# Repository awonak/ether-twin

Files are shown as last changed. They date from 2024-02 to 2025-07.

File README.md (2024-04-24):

# Ether Twin

A platform for sharing control voltage and audio over RJ45 shielded network cable

Note: These modules are still a work in progress and may contain errors.

## Ether Twin v1 - Stand-alone

Stand-alone passive desktop version.

Follow the ibom component placement guide [here](https://htmlpreview.github.io/?https://github.com/awonak/ether-twin/blob/main/ether_v1/bom/ibom.html).

Step by step build guide [here](ether_v1/README.md).

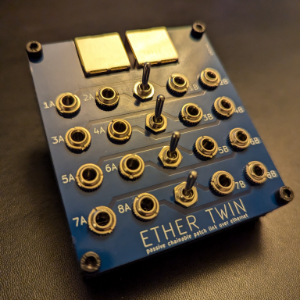
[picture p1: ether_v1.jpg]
Stand-alone Ether Twin v1


## Ether Twin v2 - 3U

Rack mount 3U 10HP version

*Photo Coming Soon*

## Ether Mix - Stand-alone

Stand-alone passive mixer

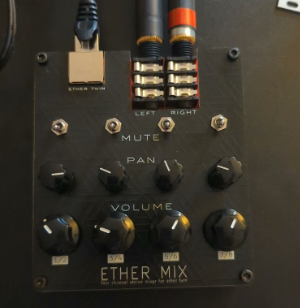
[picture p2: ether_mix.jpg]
ether-mix Ether Mix


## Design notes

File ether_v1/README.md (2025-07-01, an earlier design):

# Ether Twin v1

Tutorial Video:
https://youtu.be/pQHyfLVjiQw?si=90aeZab5XTt6bDr_

## Bill of Materials

| Reference(s) | Qty | Value | Supplier Link |
|-|-|-|-|
| J1 - J16  | 16 | Thonkiconn 3.5mm Mono Jack | https://www.thonk.co.uk/shop/thonkiconn/ |
| J17, J18 | 2 | Ethernet Connectors | https://www.mouser.com/ProductDetail/571-1-406541-5 |
| S1, S2, S3, S4 | 4 | DPDT Switch ON-ON | https://www.thonk.co.uk/shop/sub-mini-toggle-switches/ |
| S5 | 1 | 1PDT Slide Swith ON-ON | https://www.mouser.com/ProductDetail/611-JS102011SAQN |

## Build Guide v1.2

### Solder the components to the main PCB

Follow the ibom component placement guide [here](https://htmlpreview.github.io/?https://github.com/awonak/ether-twin/blob/main/ether_v1/bom/ibom.html).

1. Start by soldering the Ground Select switch S5

1. Place the two Ethernet Jacks. Begin by tacking one mounting hole lug on each Ethernet Jack. Press firmly on the jack while heating the tacked solder to ensure a snug fit.

1. Once the Ethernet Jack lugs are soldered and the jacks are flush against the PCB, then proceed to solder the 8 jack pins. (Pro tip; smear a bit of rosin flux against the pins, then drag a large bead of solder across the pins.)

1. Next, place all 16 cv jacks on the PCB. Attach the top panel, and screw nuts on the 4 corner jacks to hold them in place. Now you can flip the module over and lay it down flat while soldering the cv jacks.

1. (v1.2+ only) Remove the top panel and place the 4 toggle switches. Place the top panel back on and screw on the same 4 corner nut jacks and the 4 switch nuts. Flip the module over and solder the 4 toggle switches. (Either carefully rest the module against one side of the toggle switches, or use a third-hand to hold the module.)

### Assemble the enclosure

1. Remove the top panel attached during the previous step. This will make it easier to attach the standoffs later.

1. Start by threading the loger M3 screws through the 4 mounting holes of the bottom panel.

1. Tighten the M3 nut against those screws.

1. Place the components PCB against the nuts, components facing up.

1. Tighten the 10mm nylon standoffs to the bottom panel screws sticking up from the components PCB.

1. Attach the top panel to the component pcb and screw on all 16 cv jack nuts and 4 toggle switch nuts.

1. Screw the shorter M3 screws into the top panel mounting holes and into the standoffs.

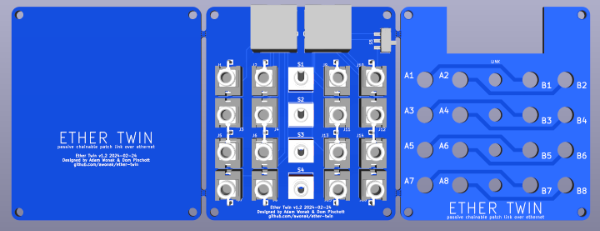
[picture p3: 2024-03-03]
ether_v1.png

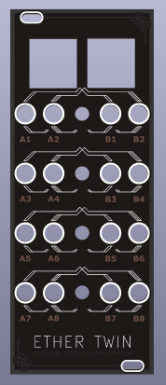
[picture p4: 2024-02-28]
ether_v2_panel.png

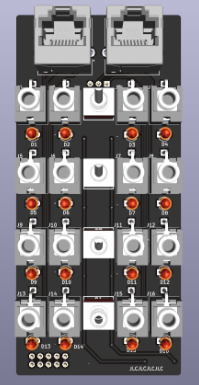
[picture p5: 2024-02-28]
ether_v2_front.png

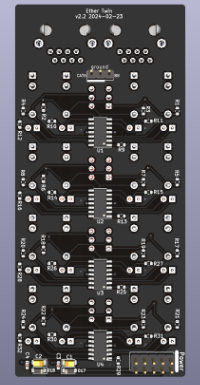
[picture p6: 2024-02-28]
ether_v2_back.png

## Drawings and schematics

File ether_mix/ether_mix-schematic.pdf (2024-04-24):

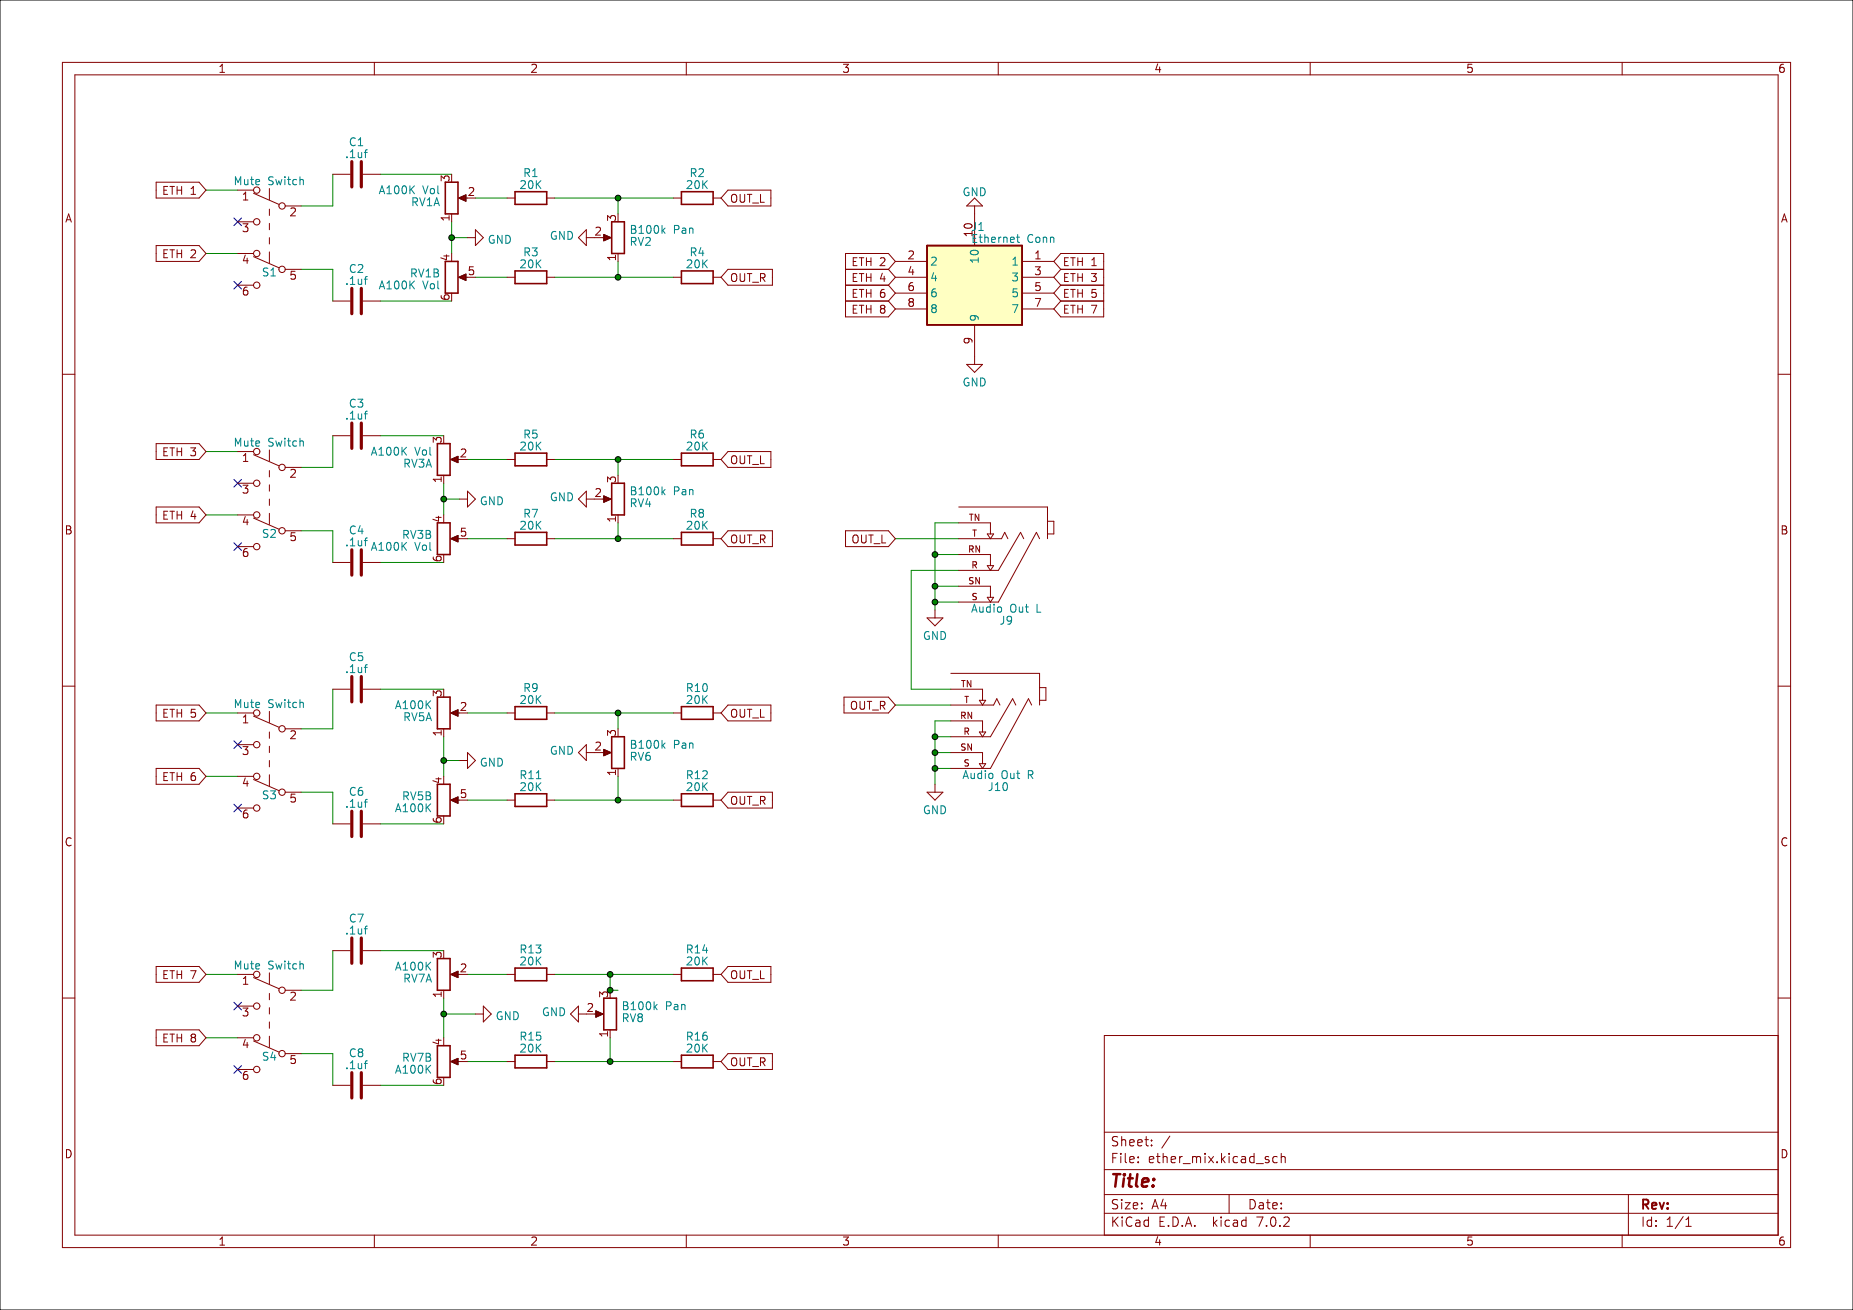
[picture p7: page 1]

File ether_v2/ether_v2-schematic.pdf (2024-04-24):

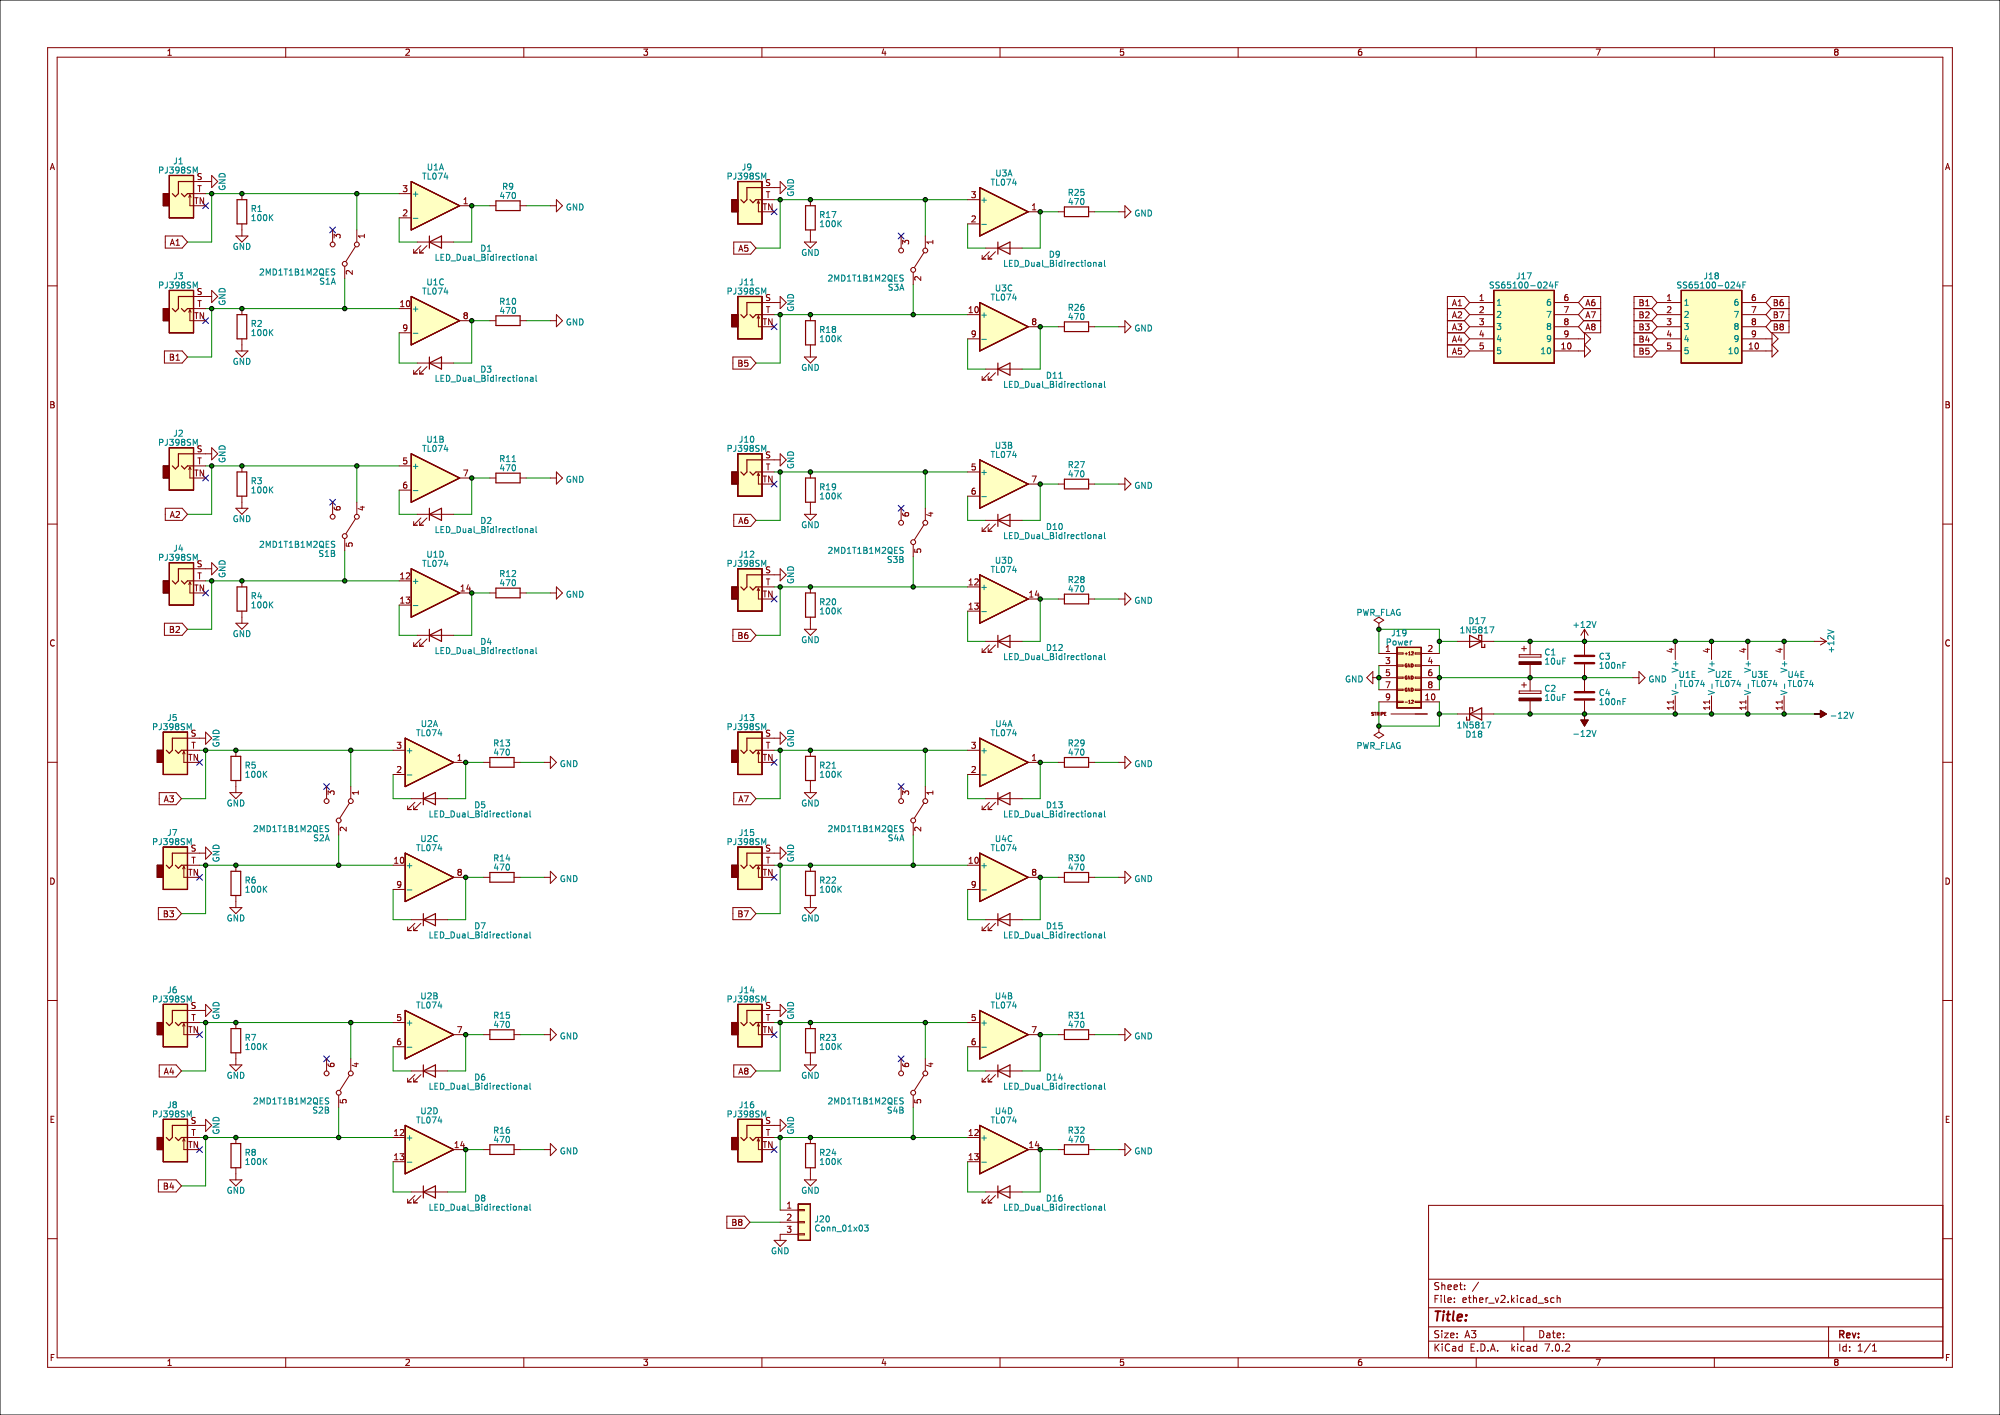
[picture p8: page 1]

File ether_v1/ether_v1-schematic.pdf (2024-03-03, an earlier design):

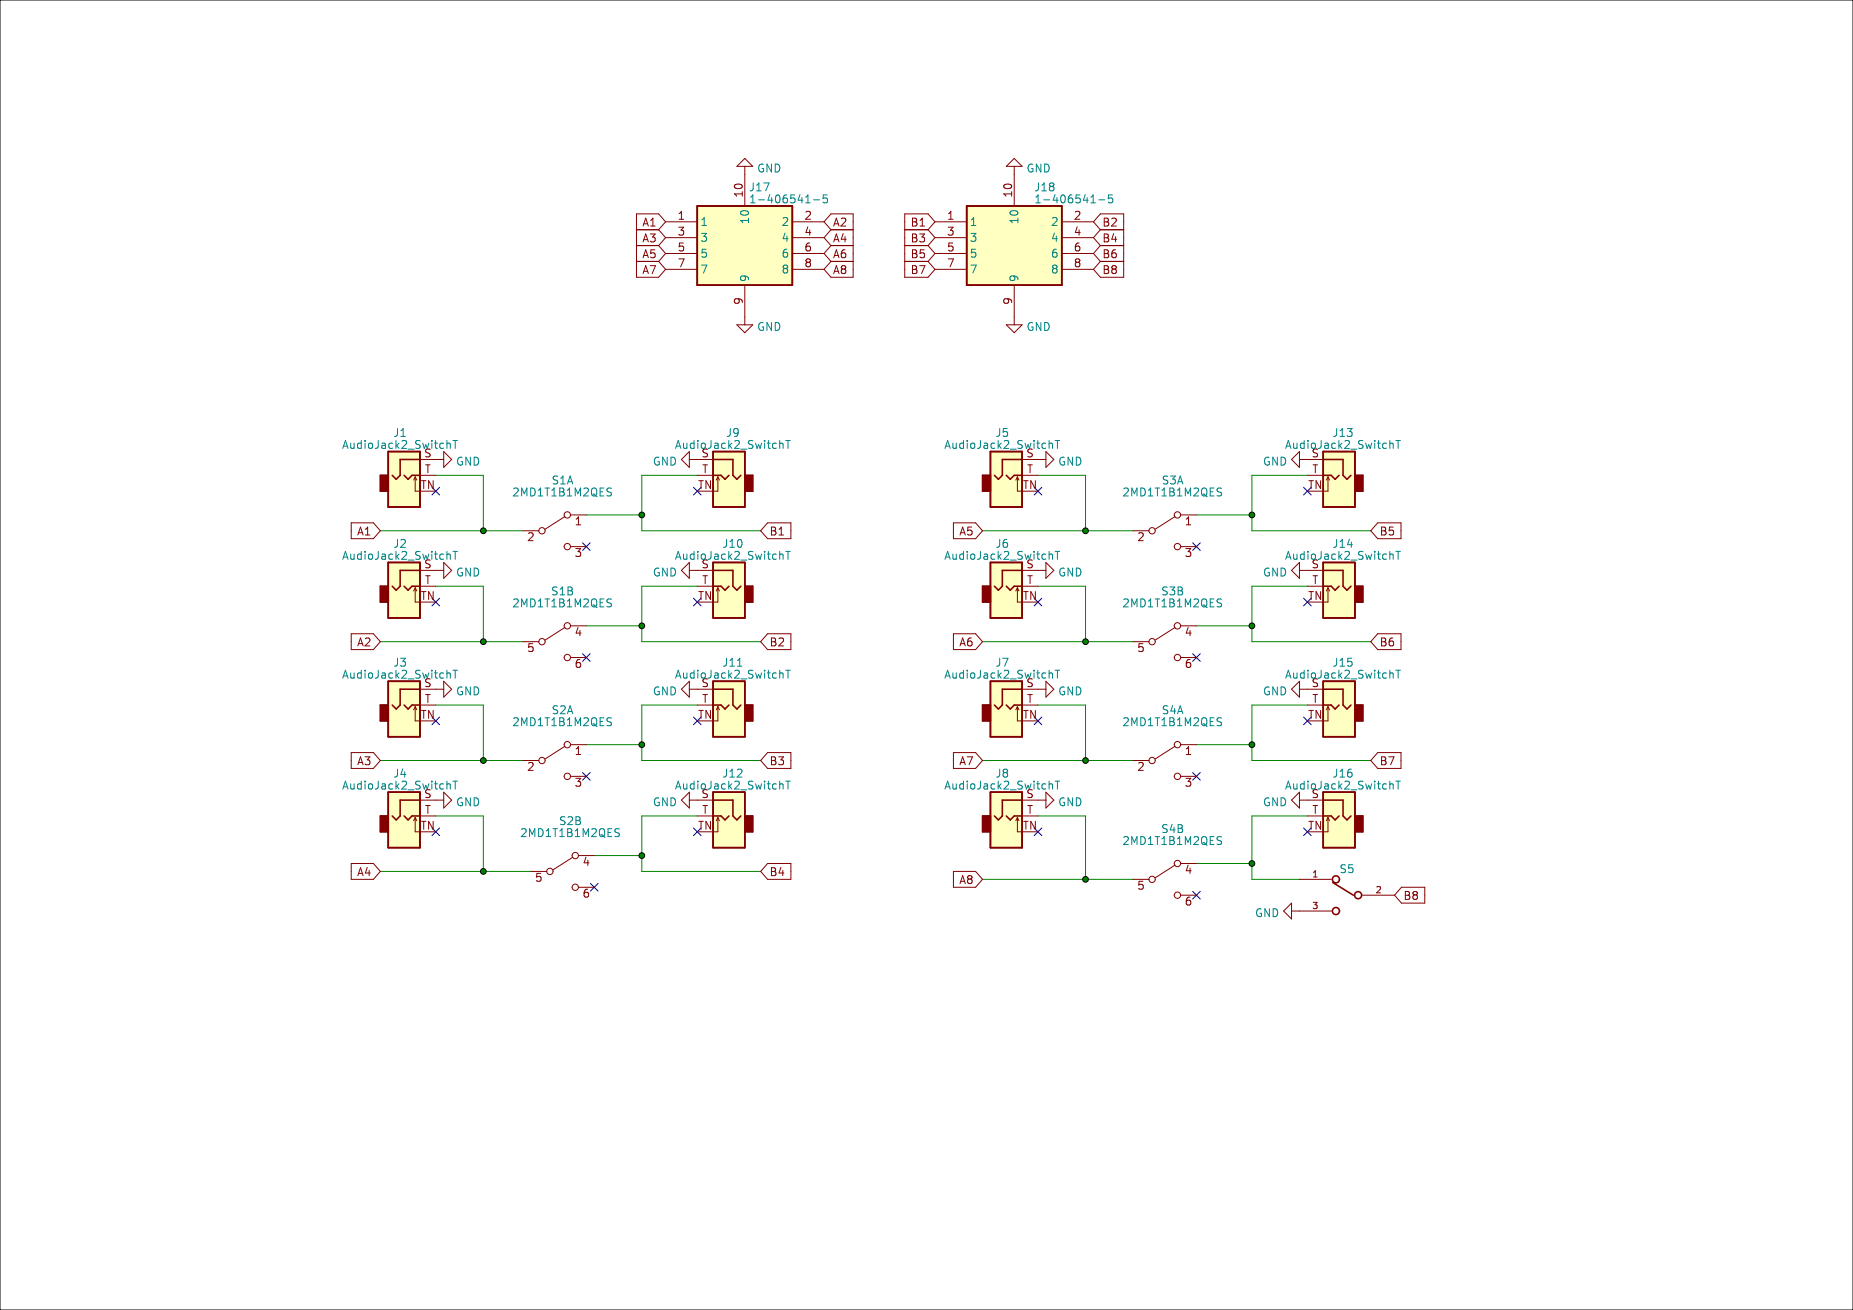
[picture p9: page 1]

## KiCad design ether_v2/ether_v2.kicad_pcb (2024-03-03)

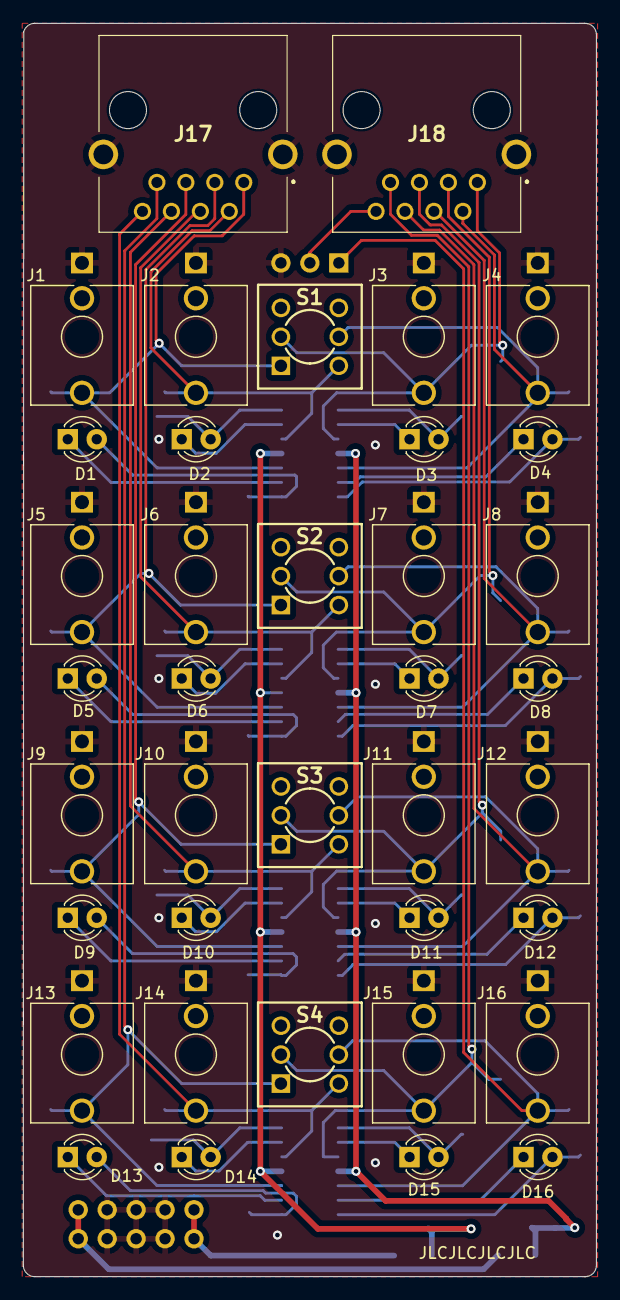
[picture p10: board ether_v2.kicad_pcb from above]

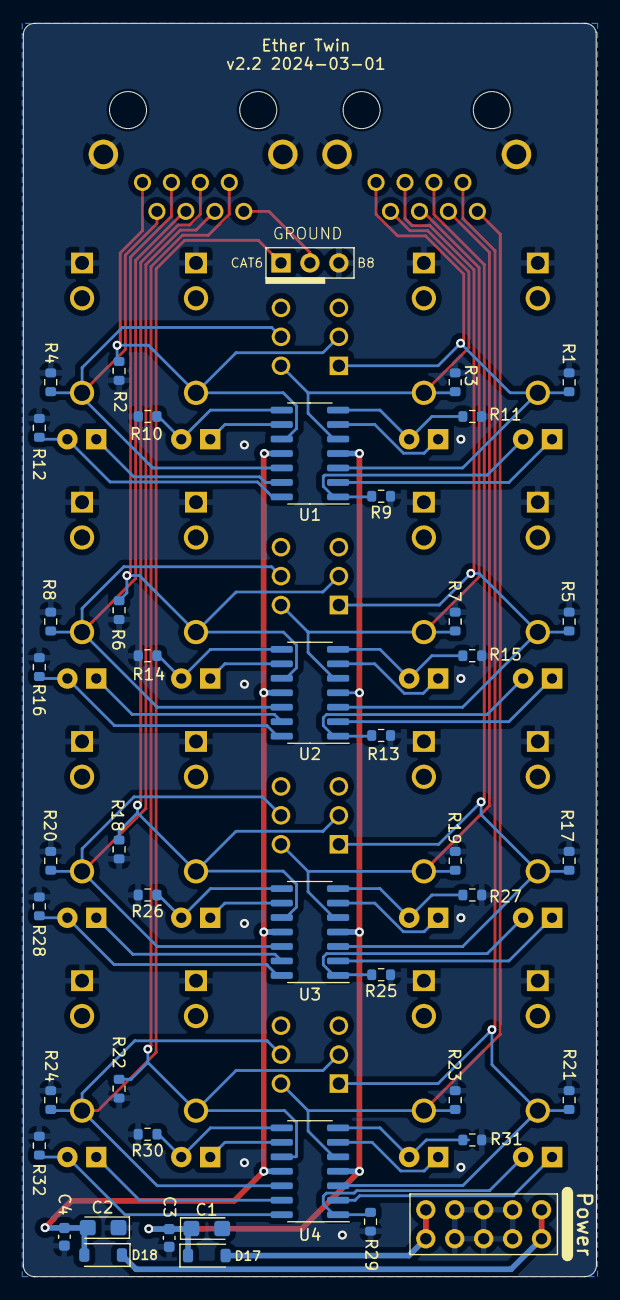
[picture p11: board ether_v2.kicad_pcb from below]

Board: 2 copper layers, 50.3 x 110.0 mm, 82 parts (44 on the bottom side), 54 nets.

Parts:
C1, C2: 10uF; CP_EIA-3216-18_Kemet-A
C3, C4: 100nF; C_0603_1608Metric
D1, D2, D3, D4, D5, D6, D7, D8, D9, D10, D11, D12, D13, D14, D15, D16: LED_Dual_Bidirectional; LED_D3.0mm
D17, D18: 1N5817; D_SOD-123
J1, J2, J3, J4, J5, J6, J7, J8, J9, J10, J11, J12, J13, J14, J15, J16: PJ398SM; Jack_3.5mm_QingPu_WQP-PJ398SM_Vertical_CircularHoles_3dModel
J17, J18: SS65100-024F; SS65100024F
J19: Power; Pins_2x05_2.54mm_TH_Europower
J20: Conn_01x03; PinHeader_1x03_P2.54mm_Vertical
R1, R2, R3, R4, R5, R6, R7, R8, R17, R18, R19, R20, R21, R22, R23, R24: 100K; R_0603_1608Metric
R9, R10, R11, R12, R13, R14, R15, R16, R25, R26, R27, R28, R29, R30, R31, R32: 470; R_0603_1608Metric
S1, S2, S3, S4: 2MD1T1B1M2QES
U1, U2, U3, U4: TL074; SO-14_3.9x8.65mm_P1.27mm

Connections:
+12V: C1.1, C3.1, D17.1 (K), U1.4 (V+), U2.4 (V+), U3.4 (V+), U4.4 (V+)
-12V: C2.2, C4.2, D18.2 (A), U1.11 (V-), U2.11 (V-), U3.11 (V-), U4.11 (V-)
A1: J1.T, J17.1, R1.2, S1.1 (A), U1.3 (+)
A2: J2.T, J17.2, R3.2, S1.4 (A), U1.5 (+)
A3: J5.T, J17.3, R5.2, S2.1 (A), U2.3 (+)
A4: J6.T, J17.4, R7.2, S2.4 (A), U2.5 (+)
A5: J9.T, J17.5, R17.2, S3.1 (A), U3.3 (+)
A6: J10.T, J17.6, R19.2, S3.4 (A), U3.5 (+)
A7: J13.T, J17.7, R21.2, S4.1 (A), U4.3 (+)
A8: J14.T, J17.8, R23.2, S4.4 (A), U4.5 (+)
B1: J3.T, J18.1, R2.2, S1.2 (B), U1.10 (+)
B2: J4.T, J18.2, R4.2, S1.5 (B), U1.12 (+)
B3: J7.T, J18.3, R6.2, S2.2 (B), U2.10 (+)
B4: J8.T, J18.4, R8.2, S2.5 (B), U2.12 (+)
B5: J11.T, J18.5, R18.2, S3.2 (B), U3.10 (+)
B6: J12.T, J18.6, R20.2, S3.5 (B), U3.12 (+)
B7: J15.T, J18.7, R22.2, S4.2 (B), U4.10 (+)
B8: J18.8, J20.2
GND: C1.2, C2.1, C3.2, C4.1, J1.S, J2.S, J3.S, J4.S, J5.S, J6.S, J7.S, J8.S, J9.S, J10.S, J11.S, J12.S, J13.S, J14.S, J15.S, J16.S, J17.9, J17.10, J18.9, J18.10, J19.3 (GND), J19.4 (GND), J19.5 (GND), J19.6 (GND), J19.7 (GND), J19.8 (GND), J20.3, R1.1, R2.1, R3.1, R4.1, R5.1, R6.1, R7.1, R8.1, R9.1, R10.2, R11.1, R12.2, R13.1, R14.2, R15.1, R16.2, R17.1, R18.1, R19.1, R20.1, R21.1, R22.1, R23.1, R24.1, R25.1, R26.2, R27.1, R28.2, R29.1, R30.2, R31.1, R32.2
unnamed: D1.2 (A), R9.2, U1.1
unnamed: D1.1 (K), U1.2 (-)
unnamed: D2.2 (A), R11.2, U1.7
unnamed: D2.1 (K), U1.6 (-)
unnamed: D3.2 (A), R10.1, U1.8
unnamed: D3.1 (K), U1.9 (-)
unnamed: D4.2 (A), R12.1, U1.14
unnamed: D4.1 (K), U1.13 (-)
unnamed: D5.2 (A), R13.2, U2.1
unnamed: D5.1 (K), U2.2 (-)
unnamed: D6.2 (A), R15.2, U2.7
unnamed: D6.1 (K), U2.6 (-)
unnamed: D7.2 (A), R14.1, U2.8
unnamed: D7.1 (K), U2.9 (-)
unnamed: D8.2 (A), R16.1, U2.14
unnamed: D8.1 (K), U2.13 (-)
unnamed: D9.2 (A), R25.2, U3.1
unnamed: D9.1 (K), U3.2 (-)
unnamed: D10.2 (A), R27.2, U3.7
unnamed: D10.1 (K), U3.6 (-)
unnamed: D11.2 (A), R26.1, U3.8
unnamed: D11.1 (K), U3.9 (-)
unnamed: D12.2 (A), R28.1, U3.14
unnamed: D12.1 (K), U3.13 (-)
unnamed: D13.2 (A), R29.2, U4.1
unnamed: D13.1 (K), U4.2 (-)
unnamed: D14.2 (A), R31.2, U4.7
unnamed: D14.1 (K), U4.6 (-)
unnamed: D15.2 (A), R30.1, U4.8
unnamed: D15.1 (K), U4.9 (-)
unnamed: D16.2 (A), R32.1, U4.14
unnamed: D16.1 (K), U4.13 (-)
unnamed: D17.2 (A), J19.1 (+12V), J19.2 (+12V)
unnamed: D18.1 (K), J19.9 (-12V), J19.10 (-12V)
unnamed: J16.T, J20.1, R24.2, S4.5 (B), U4.12 (+)

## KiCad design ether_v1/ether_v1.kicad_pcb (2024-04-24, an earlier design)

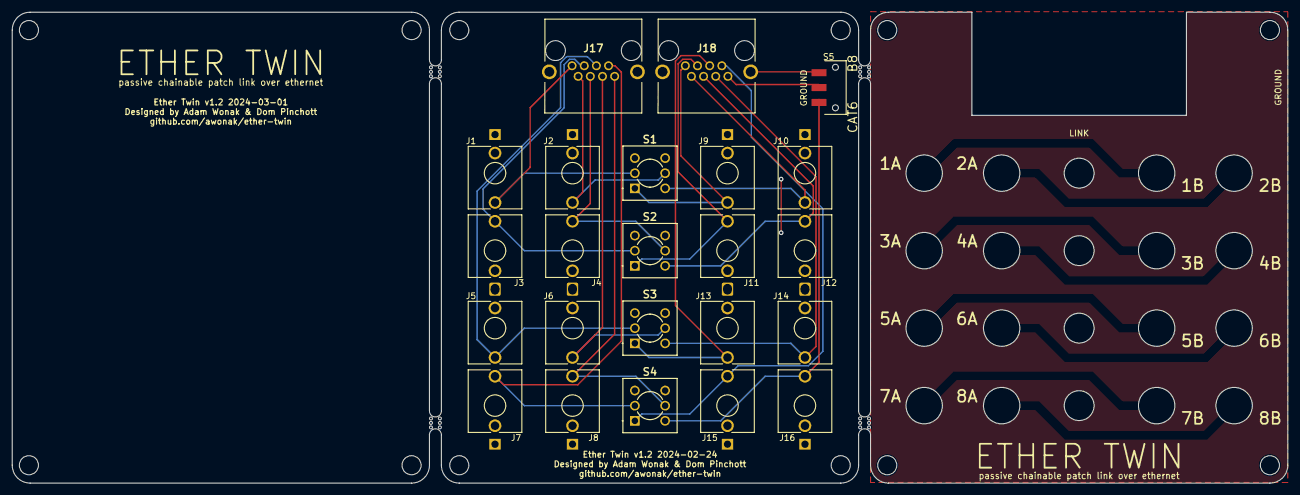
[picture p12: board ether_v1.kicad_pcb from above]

Board: 2 copper layers, 214.0 x 79.0 mm, 27 parts (0 on the bottom side), 18 nets.

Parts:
J1, J2, J3, J4, J5, J6, J7, J8, J9, J10, J11, J12, J13, J14, J15, J16: AudioJack2_SwitchT; Jack_3.5mm_QingPu_WQP-PJ398SM_Vertical_CircularHoles_3dModel
J17, J18: 1-406541-5; 14065415
MH: VAL**; mouse-bite-2mm-slot
MH#2, MH#3, MH#4: VAL**; mouse-bite-2mm-slot
S1, S2, S3, S4: 2MD1T1B1M2QES
S5: JS102011SAQN; SW_JS102011SAQN

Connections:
A1: J1.T, J17.1, S1.2 (B)
A2: J2.T, J17.2, S1.5 (B)
A3: J3.T, J17.3, S2.2 (B)
A4: J4.T, J17.4, S2.5 (B)
A5: J5.T, J17.5, S3.2 (B)
A6: J6.T, J17.6, S3.5 (B)
A7: J7.T, J17.7, S4.2 (B)
A8: J8.T, J17.8, S4.5 (B)
B1: J9.T, J18.1, S1.1 (A)
B2: J10.T, J18.2, S1.4 (A)
B3: J11.T, J18.3, S2.1 (A)
B4: J12.T, J18.4, S2.4 (A)
B5: J13.T, J18.5, S3.1 (A)
B6: J14.T, J18.6, S3.4 (A)
B7: J15.T, J18.7, S4.1 (A)
B8: J18.8, S5.2
GND: J1.S, J2.S, J3.S, J4.S, J7.S, J8.S, J9.S, J10.S, J11.S, J12.S, J15.S, J16.S, J17.9, J17.10, J18.9, J18.10, S5.3
unnamed: J16.T, S4.4 (A), S5.1

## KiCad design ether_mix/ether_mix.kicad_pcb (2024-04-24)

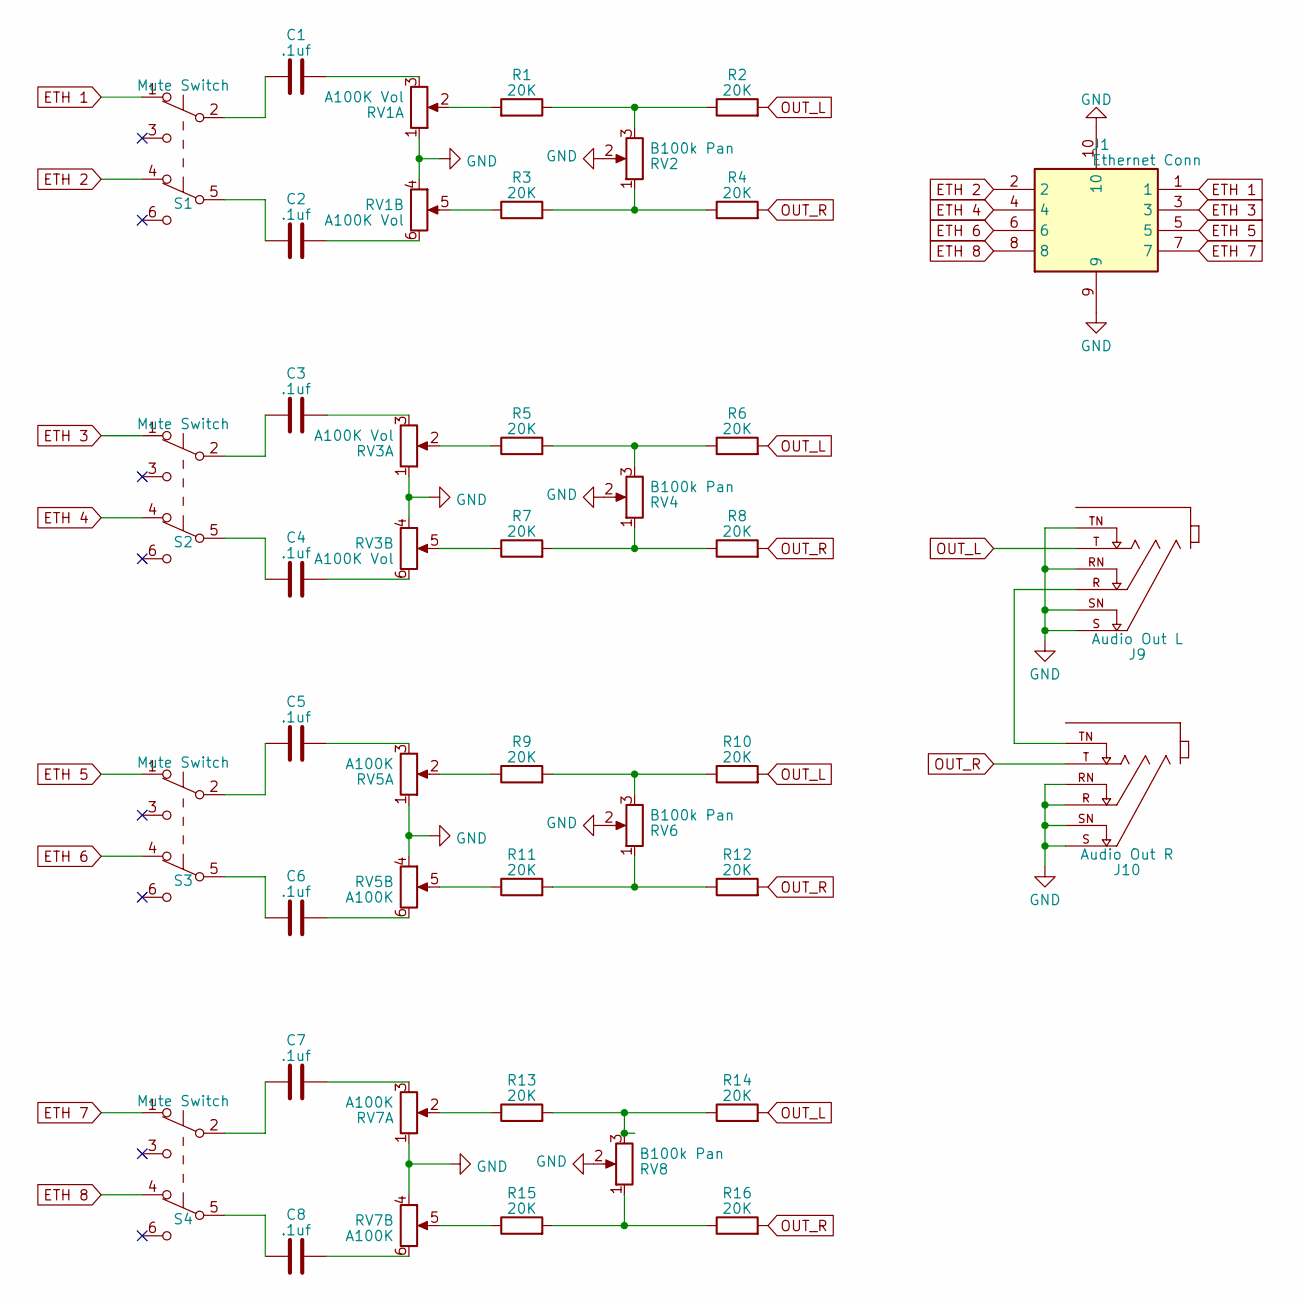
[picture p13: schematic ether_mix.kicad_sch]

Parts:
C1, C2, C3, C4, C5, C6, C7, C8: .1uf; C_0603_1608Metric
J1: Ethernet Conn; 14065415; Mouser Part Number 571-1-406541-5
J9: Audio Out L; NEUTRIK_NRJ6HF; PARTREV 19.02.2021
J10: Audio Out R; NEUTRIK_NRJ6HF; PARTREV 19.02.2021
R1, R2, R3, R4, R5, R6, R7, R8, R9, R10, R11, R12, R13, R14, R15, R16: 20K; R_0603_1608Metric
RV1, RV3: A100K Vol; Potentiometer_Alpha_RD902F-40-00D_Dual_Vertical_CircularHol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
RV2, RV4, RV6, RV8: B100k Pan; Potentiometer_Alpha_RD901F-40-00D_Single_Vertical
RV5, RV7: A100K; Potentiometer_Alpha_RD902F-40-00D_Dual_Vertical_CircularHol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
S1, S2, S3, S4: Mute Switch; 2MD1T1B1M2QES; Mouser Part Number 118-2MD1T1B1M2QES

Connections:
ETH 1: J1.1, S1.1 (A)
ETH 2: J1.2, S1.4 (A)
ETH 3: J1.3, S2.1 (A)
ETH 4: J1.4, S2.4 (A)
ETH 5: J1.5, S3.1 (A)
ETH 6: J1.6, S3.4 (A)
ETH 7: J1.7, S4.1 (A)
ETH 8: J1.8, S4.4 (A)
GND: J1.9, J1.10, J9.RN, J9.S, J9.SN, J9.TN, J10.R, J10.RN, J10.S, J10.SN, RV1.1, RV1.4, RV2.2, RV3.1, RV3.4, RV4.2, RV5.1, RV5.4, RV6.2, RV7.1, RV7.4, RV8.2
unnamed: C1.1, S1.2 (B)
unnamed: C1.2, RV1.3
unnamed: C2.1, S1.5 (B)
unnamed: C2.2, RV1.6
unnamed: C3.1, S2.2 (B)
unnamed: C3.2, RV3.3
unnamed: C4.1, S2.5 (B)
unnamed: C4.2, RV3.6
unnamed: C5.1, S3.2 (B)
unnamed: C5.2, RV5.3
unnamed: C6.1, S3.5 (B)
unnamed: C6.2, RV5.6
unnamed: C7.1, S4.2 (B)
unnamed: C7.2, RV7.3
unnamed: C8.1, S4.5 (B)
unnamed: C8.2, RV7.6
unnamed: J9.R, J10.TN
unnamed: R1.1, R2.1, RV2.3
unnamed: R1.2, RV1.2
unnamed: R3.1, RV1.5
unnamed: R3.2, R4.1, RV2.1
unnamed: R5.1, RV3.2
unnamed: R5.2, R6.1, RV4.3
unnamed: R7.1, RV3.5
unnamed: R7.2, R8.1, RV4.1
unnamed: R9.1, RV5.2
unnamed: R9.2, R10.1, RV6.3
unnamed: R11.1, RV5.5
unnamed: R11.2, R12.1, RV6.1
unnamed: R13.1, RV7.2
unnamed: R13.2, R14.1, RV8.3
unnamed: R15.1, RV7.5
unnamed: R15.2, R16.1, RV8.1
OUT_L: J9.T, R2.2, R6.2, R10.2, R14.2
OUT_R: J10.T, R4.2, R8.2, R12.2, R16.2

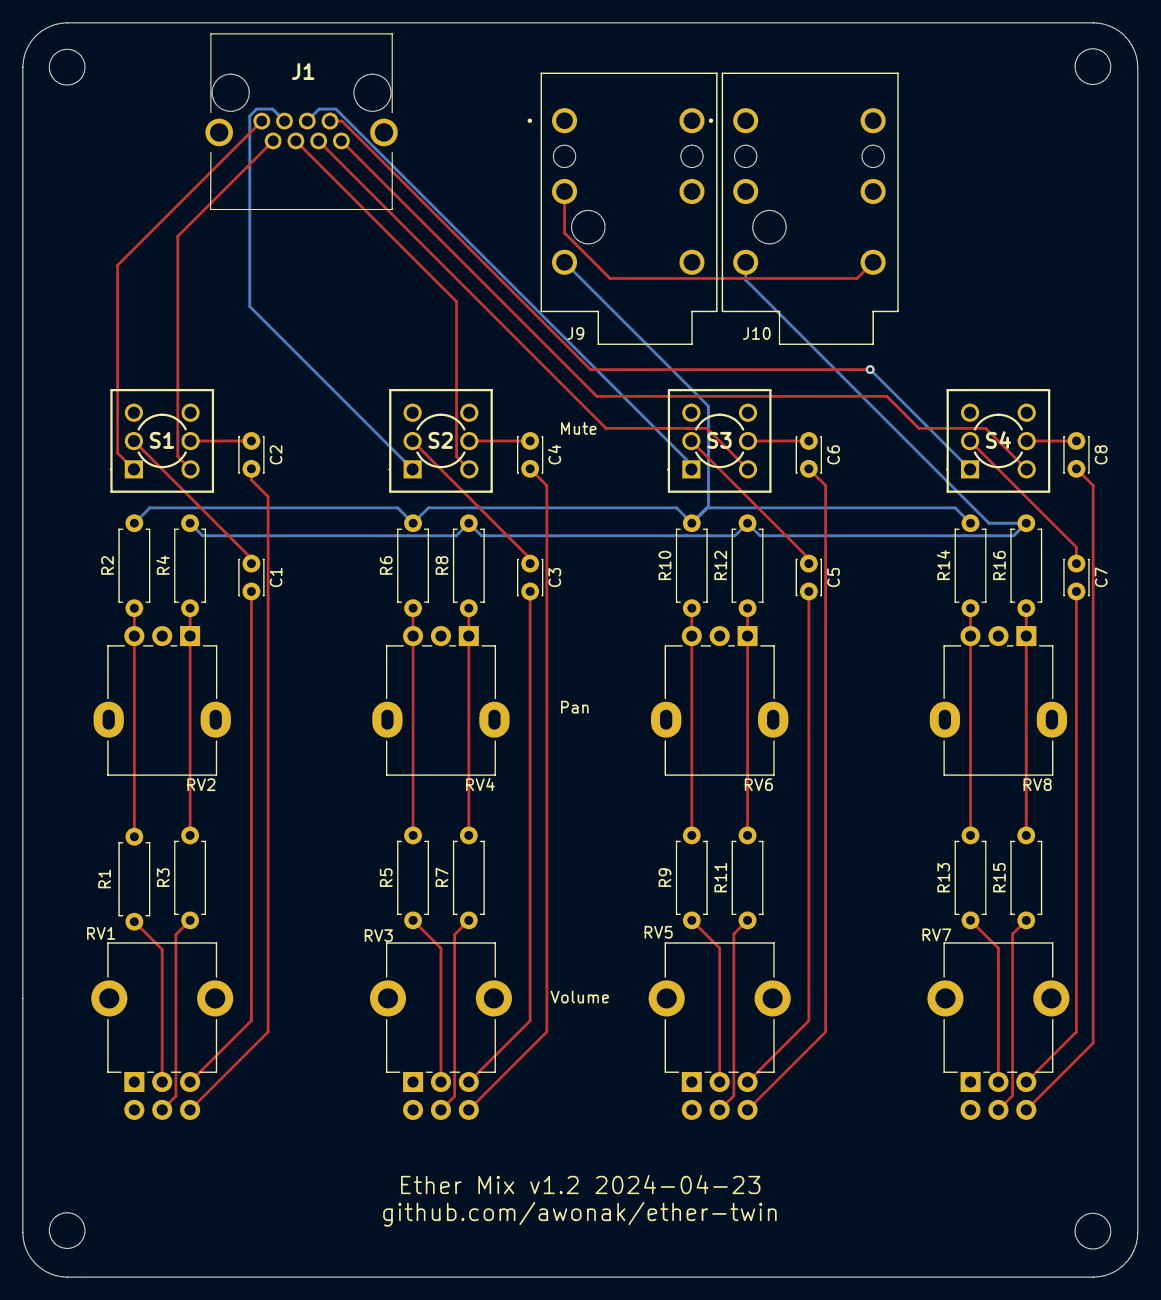
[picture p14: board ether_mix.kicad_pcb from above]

Board: 2 copper layers, 100.0 x 112.5 mm, 43 parts (0 on the bottom side), 44 nets.

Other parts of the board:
H1, H2, H3, H4: MountingHole; MountingHole_3.2mm_M3

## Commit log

2024-03-03 Add Ether Twin v1 README, bom, schematic.
    [ether_panel.kicad_pcb, ether_v1.kicad_pcb, ether_v1.kicad_sch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]
2024-03-14 add schematic for Ether Twin v2
2024-03-17 Fix incorrect placement of ground and led resistor. Fixes Odd wiring of LED in schematic. #1
    [ether_v2.kicad_pcb, ether_v2.kicad_sch]
2024-03-17 Update pcb revision silkscreen.
    [ether_v2.kicad_pcb]
2024-04-24 Add Ether Twin v2 schematic
2024-04-24 Add Ether Mix
    [ether_mix.kicad_pcb, ether_mix.kicad_sch, ether_mix_panel.kicad_pcb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]
2024-04-24 Ether v1 panel label update
    [ether_v1.kicad_pcb]
2024-04-24 fix bad merge
    [ether_v2.kicad_pcb, ether_v2.kicad_sch]
